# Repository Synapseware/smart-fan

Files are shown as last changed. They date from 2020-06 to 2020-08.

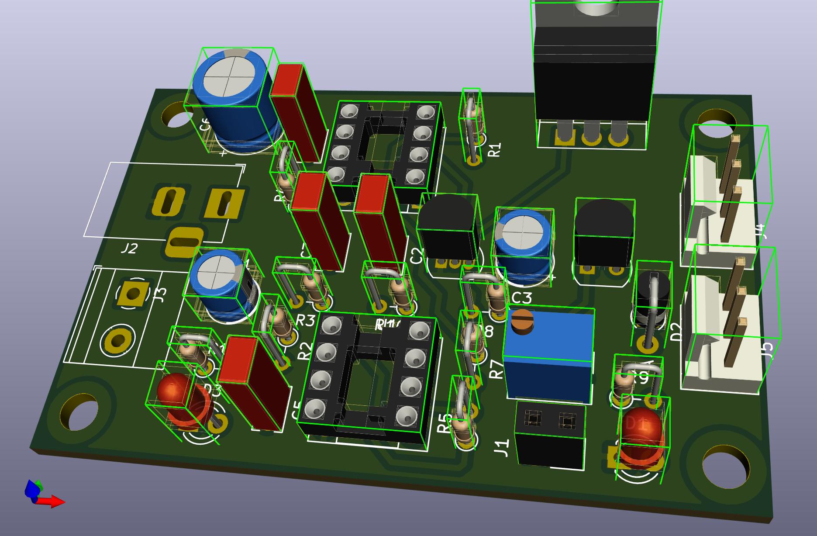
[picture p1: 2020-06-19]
analog-12v-only-smd/smart-fan-12v-only.jpg

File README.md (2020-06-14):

Smart-Fan
=========

Yet another fan project...

# Projects

## Analog
Simple analog fan controller (on/off) using a TMP35.

## Case Cooling
Smart fan controller using tachometer feedback and either PWM (4-pin) or voltage control (3-pin) and a variety of temperature sensors (analog, 1-wire, etc.).  Used to provide automatic temperature control for things like my printer enclosure for air circulation, inlet air control, etc.

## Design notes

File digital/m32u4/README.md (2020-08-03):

Arduino Leonardo ATMega32u4
===========================

Based on the m32u4 Leonardo board, this fan controller uses digital one-wire temperature sensors and a simple USB-UART for fan programming.

## Pin mappings
https://www.arduino.cc/en/Hacking/PinMapping32u4
```
Pin Name							Mapped Pin Name
1	PE6 (INT.6/AIN0)				Digital pin 7
2	UVcc							+5V
3	D-								RD-
4	D+								RD+
5	UGnd							UGND
6	UCap							UCAP
7	VUSB							VBus
8	(SS/PCINT0) PB0					RXLED
9	(PCINT1/SCLK) PB1				SCK
10	(PDI/PCINT2/MOSI) PB2			MOSI
11	(PDO/PCINT3/MISO) PB3			MISO
12	(PCINT7/OC0A/OC1C/#RTS) PB7		Digital pin 11 (PWM)
13	RESET							RESET
14	Vcc								+5V
15	GND								GND
16	XTAL2							XTAL2
17	XTAL1							XTAL1
18	(OC0B/SCL/INT0) PD0				Digital pin 3 (SCL)(PWM)
19	(SDA/INT1) PD1					Digital pin 2 (SDA)
20	(RX D1/AIN1/INT2) PD2			Digital pin 0 (RX)
21	(TXD1/INT3) PD3					Digital pin 1 (TX)
22	(XCK1/#CTS) PD5					TXLED
23	GND1							GND
24	AVCC							AVCC
25	(ICP1/ADC8) PD4					Digital pin 4
26	(T1/#OC4D/ADC9) PD6				Digital pin 12
27	(T0/OC4D/ADC10) PD7				Digital Pin 6 (PWM)
28	(ADC11/PCINT4) PB4				Digital pin 8
29	(PCINT5/OC1A/#OC4B/ADC12) PB5	Digital Pin 9 (PWM)
30	(PCINT6/OC1B/OC4B/ADC13) PB6	Digital Pin 10 (PWM)
31	(OC3A/#0C4A) PC6				Digital Pin 5 (PWM)
32	(ICP3/CLK0/)0C4A) PC7			Digital Pin 13 (PWM)
33	(#HWB) PE2						HWB
34	Vcc1							+5V
35	GND2							GND
36	(ADC7/TDI) PF7					Analog In 0
37	(ADC6/TDO) PF6					Analog In 1
38	(ADC5/TMS) PF5					Analog In 2
39	(ADC4/TCK) PF4					Analog In 3
40	(ADC1) PF1						Analog In 4
41	(ADC0) PF0						Analog In 5
42	AREF							AEF
43	GND3							GND
44	AVCC1							AVCC
```

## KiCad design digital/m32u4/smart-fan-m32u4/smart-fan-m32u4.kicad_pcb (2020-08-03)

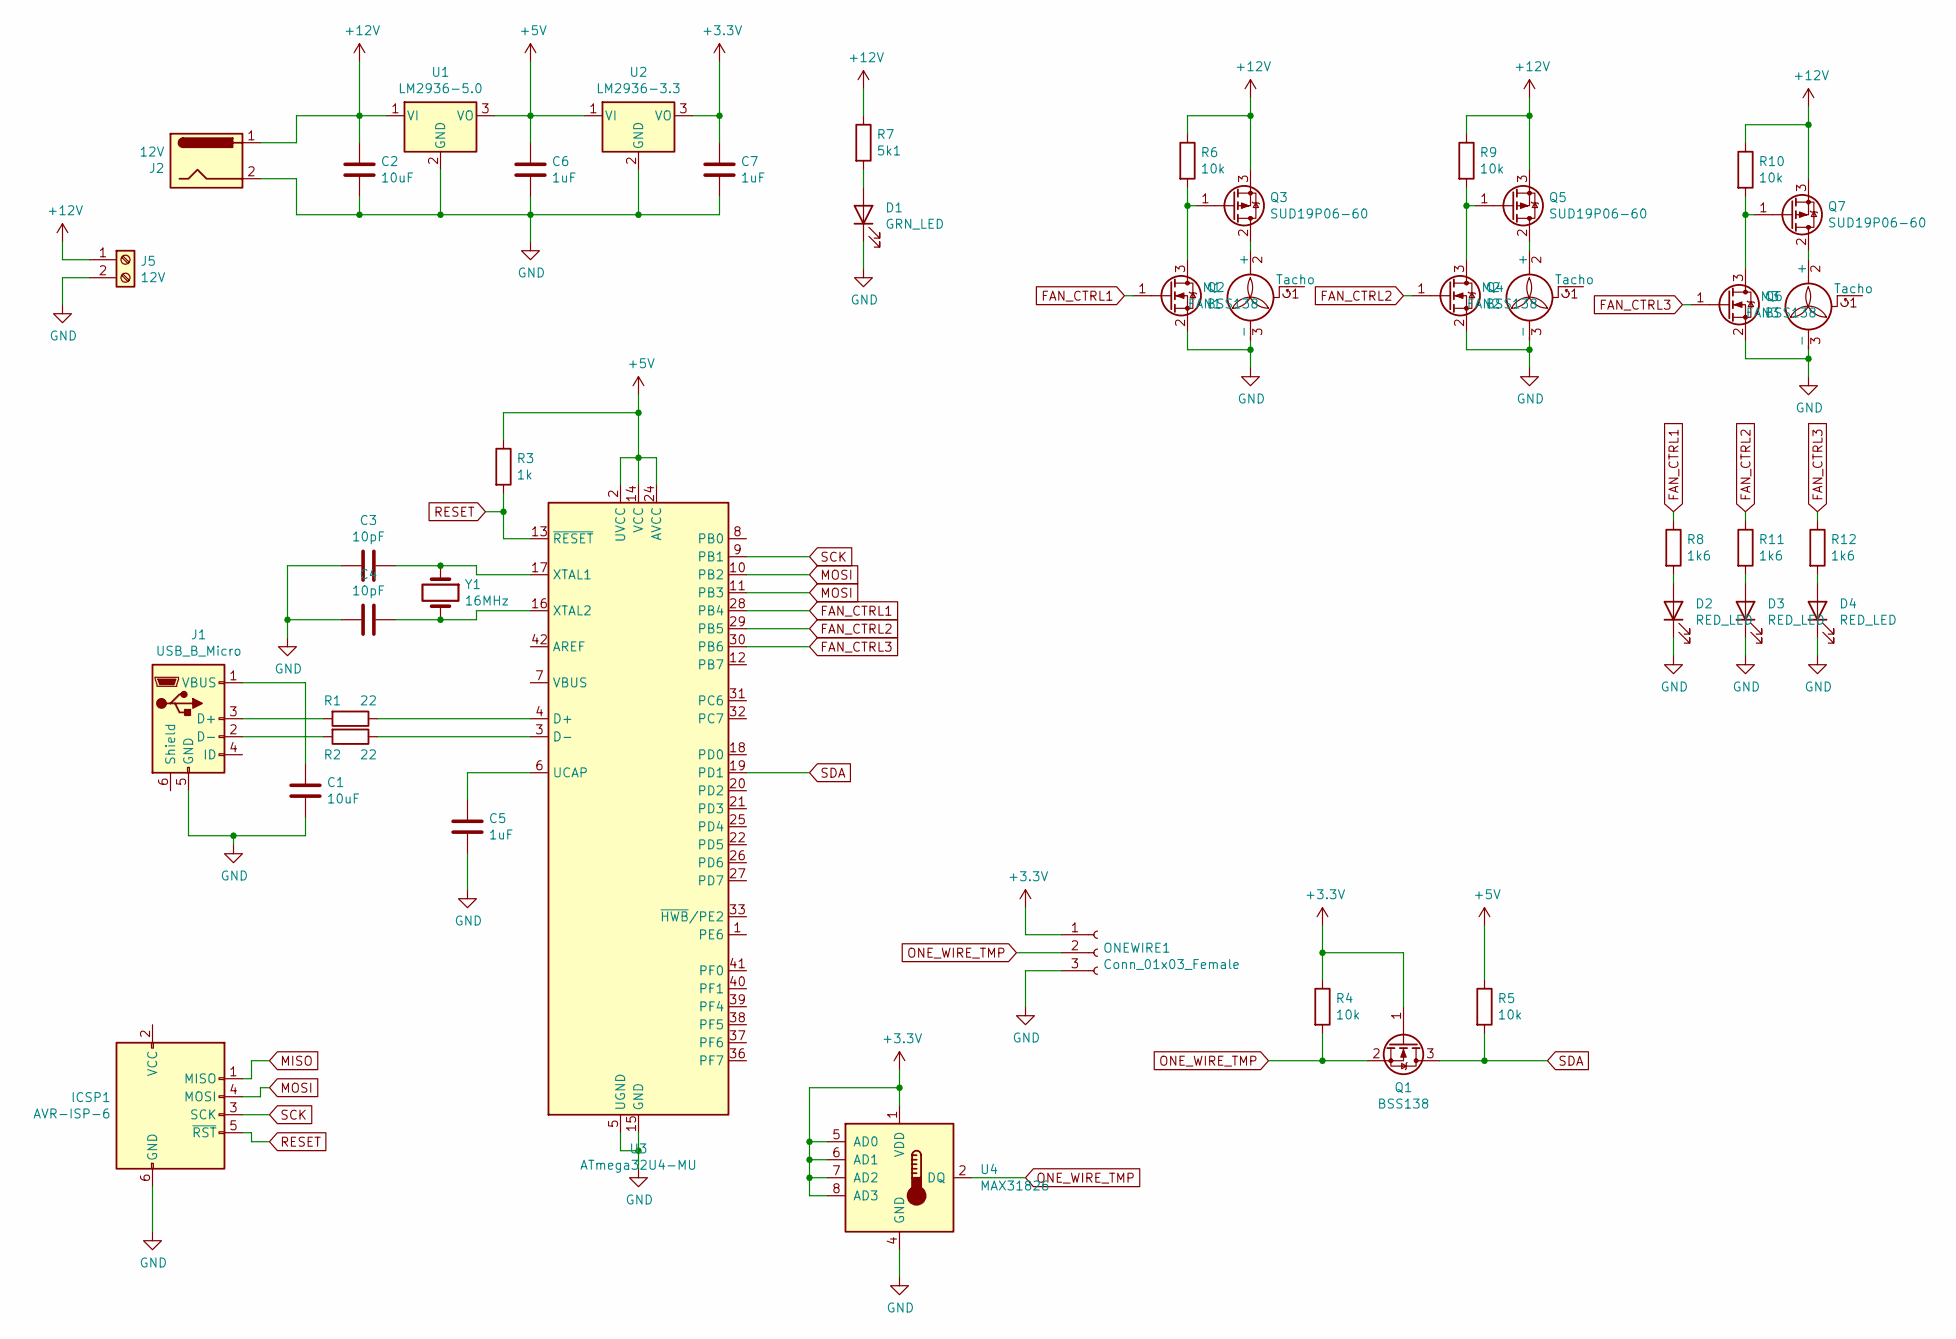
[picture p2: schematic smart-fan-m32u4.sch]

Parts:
C1, C2: 10uF; C_0805_2012Metric
C3, C4: 10pF; C_0805_2012Metric
C5, C6, C7: 1uF; C_0805_2012Metric
D1: GRN_LED; LED_0805_2012Metric
D2, D3, D4: RED_LED; LED_0805_2012Metric
ICSP1: AVR-ISP-6; PinHeader_2x03_P2.54mm_Vertical
J1: USB_B_Micro; USB_Micro-B_Amphenol_10104110_Horizontal
J2: 12V; BarrelJack_Horizontal
J5: 12V; TerminalBlock_Phoenix_MKDS-1,5-2-5.08_1x02_P5.08mm_Horizont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
M1: FAN1; FanPinHeader_1x03_P2.54mm_Vertical
M2: FAN2; FanPinHeader_1x03_P2.54mm_Vertical
M3: FAN3; FanPinHeader_1x03_P2.54mm_Vertical
ONEWIRE1: Conn_01x03_Female; PinSocket_1x03_P2.54mm_Vertical
Q1, Q2, Q4, Q6: BSS138; SOT-23
Q3, Q5, Q7: SUD19P06-60; TO-252-2
R1, R2: 22; R_0805_2012Metric
R3: 1k; R_0805_2012Metric
R4, R5, R6, R9, R10: 10k; R_0805_2012Metric
R7: 5k1; R_0805_2012Metric
R8, R11, R12: 1k6; R_0805_2012Metric
U1: LM2936-5.0; SOT-223-3_TabPin2
U2: LM2936-3.3; SOT-223-3_TabPin2
U3: ATmega32U4-MU; QFN-44-1EP_7x7mm_P0.5mm_EP5.2x5.2mm
U4: MAX31826; MSOP-8_3x3mm_P0.65mm
Y1: 16MHz; Crystal_SMD_0603-2Pin_6.0x3.5mm

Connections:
+3V3: C7.1, ONEWIRE1.1, Q1.1 (G), R4.1, U2.3 (VO), U4.1 (VDD), U4.5 (AD0), U4.6 (AD1), U4.7 (AD2), U4.8 (AD3)
+5V: C6.1, R3.1, R5.1, U1.3 (VO), U2.1 (VI), U3.2 (UVCC), U3.14 (VCC), U3.24 (AVCC), U3.34 (VCC), U3.44 (AVCC)
+12V: C2.1, J2.1, J5.1, Q3.3 (S), Q5.3 (S), Q7.3 (S), R6.1, R7.1, R9.1, R10.1, U1.1 (VI)
FAN_CTRL1: Q2.1 (G), R8.1, U3.28 (PB4)
FAN_CTRL2: Q4.1 (G), R11.1, U3.29 (PB5)
FAN_CTRL3: Q6.1 (G), R12.1, U3.30 (PB6)
GND: C1.2, C2.2, C3.2, C4.2, C5.2, C6.2, C7.2, D1.1 (K), D2.1 (K), D3.1 (K), D4.1 (K), ICSP1.6 (GND), J1.5 (GND), J2.2, J5.2, M1.3 (-), M2.3 (-), M3.3 (-), ONEWIRE1.3, Q2.2 (S), Q4.2 (S), Q6.2 (S), U1.2 (GND), U2.2 (GND), U3.5 (UGND), U3.15 (GND), U3.23 (GND), U3.35 (GND), U3.43 (GND), U3.45 (GND), U4.4 (GND)
MISO: ICSP1.1 (MISO)
MOSI: ICSP1.4 (MOSI), U3.10 (PB2), U3.11 (PB3)
unnamed: C1.1, J1.1 (VBUS)
unnamed: C3.1, U3.17 (XTAL1), Y1.1
unnamed: C4.1, U3.16 (XTAL2), Y1.2
unnamed: C5.1, U3.6 (UCAP)
unnamed: D1.2 (A), R7.2
unnamed: D2.2 (A), R8.2
unnamed: D3.2 (A), R11.2
unnamed: D4.2 (A), R12.2
unnamed: J1.2 (D-), R2.2
unnamed: J1.3 (D+), R1.2
unnamed: M1.2 (+), Q3.2 (D)
unnamed: M2.2 (+), Q5.2 (D)
unnamed: M3.2 (+), Q7.2 (D)
unnamed: Q2.3 (D), Q3.1 (G), R6.2
unnamed: Q4.3 (D), Q5.1 (G), R9.2
unnamed: Q6.3 (D), Q7.1 (G), R10.2
unnamed: R1.1, U3.4 (D+)
unnamed: R2.1, U3.3 (D-)
ONE_WIRE_TMP: ONEWIRE1.2, Q1.2 (S), R4.2, U4.2 (DQ)
RESET: ICSP1.5 (~RST), R3.2, U3.13 (~RESET)
SCK: ICSP1.3 (SCK), U3.9 (PB1)
SDA: Q1.3 (D), R5.2, U3.19 (PD1)

Board: 2 copper layers, 43 parts (0 on the bottom side), 30 nets, no tracks yet.

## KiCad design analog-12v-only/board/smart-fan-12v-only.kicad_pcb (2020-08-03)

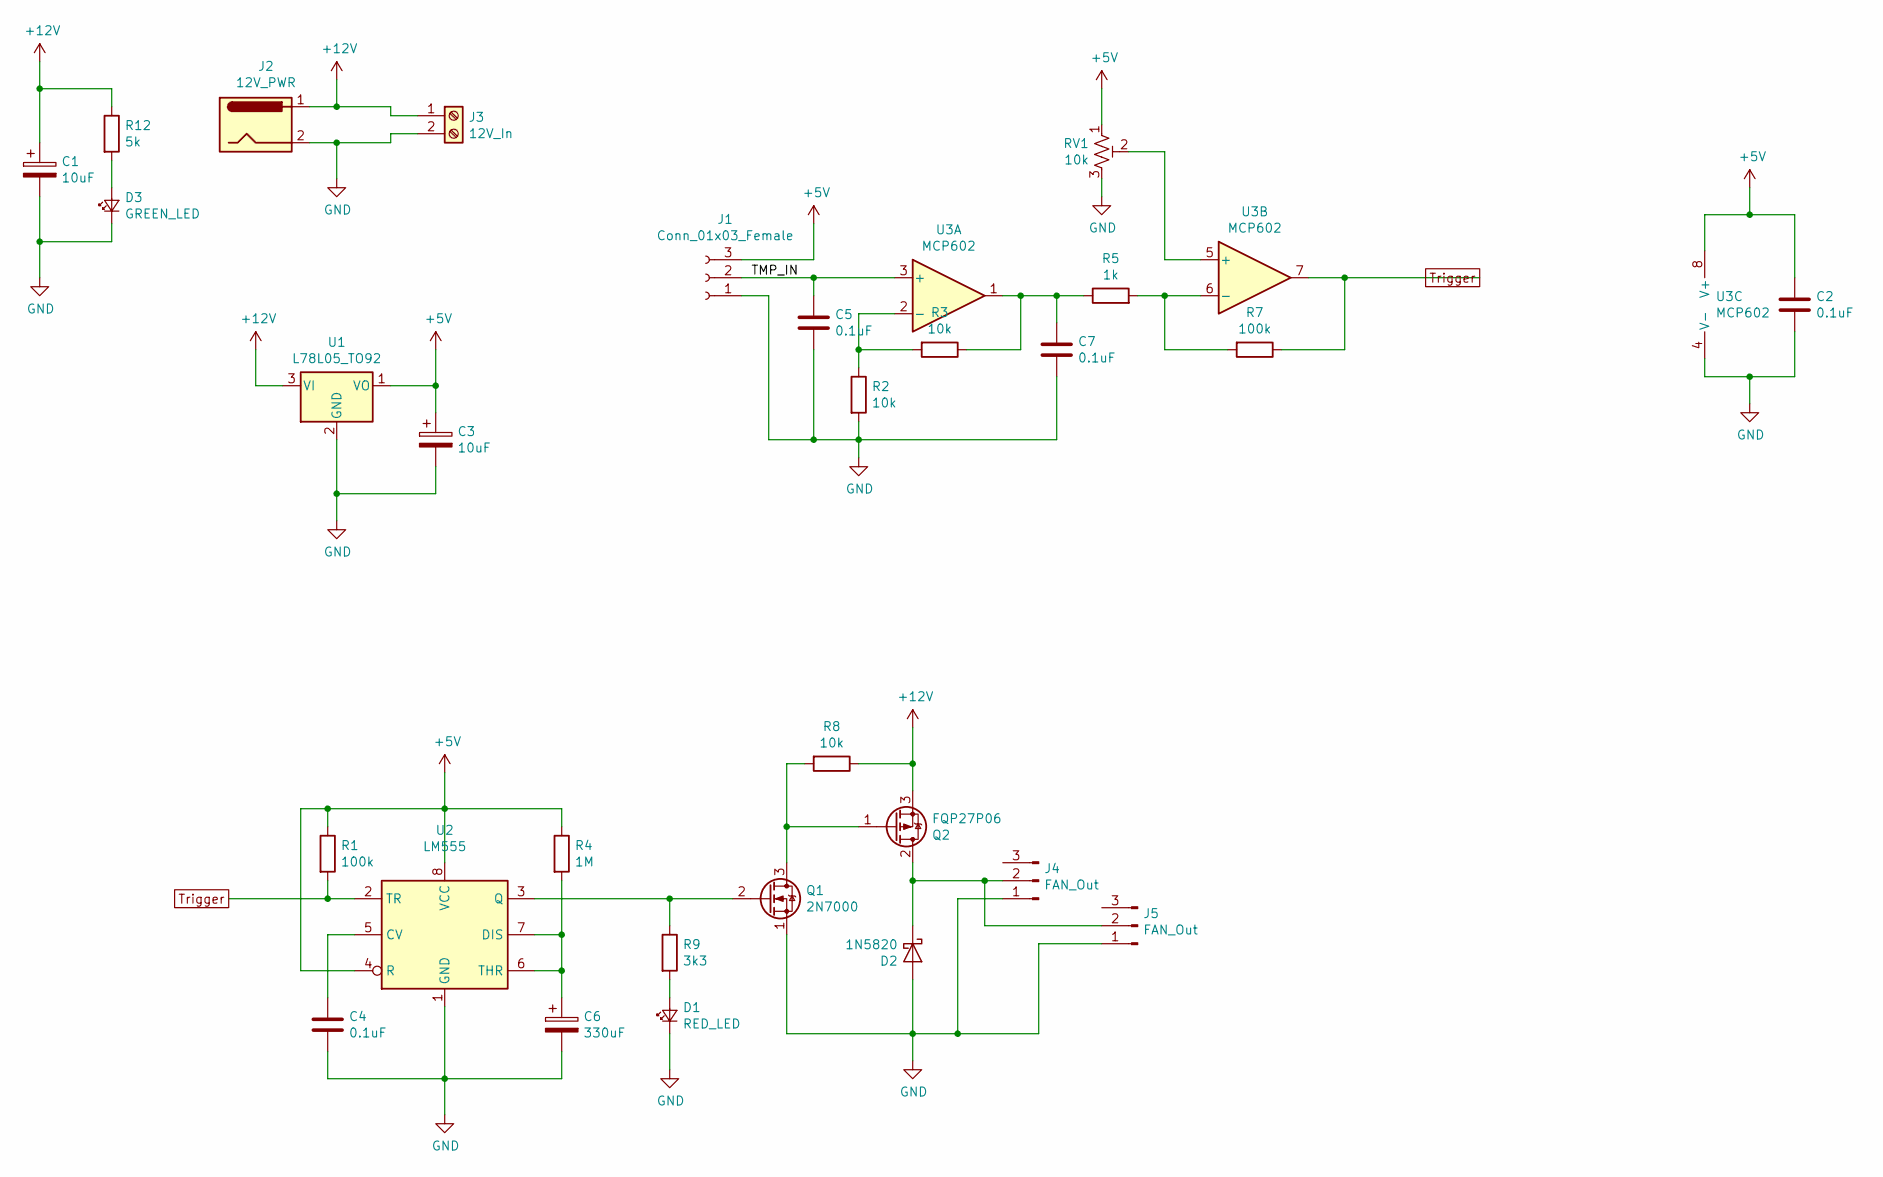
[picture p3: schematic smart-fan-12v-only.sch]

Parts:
C1, C3: 10uF; CP_Radial_D5.0mm_P2.00mm
C2, C4, C5, C7: 0.1uF; C_Rect_L4.0mm_W2.5mm_P2.50mm
C6: 330uF; CP_Radial_D7.5mm_P2.50mm
D1: RED_LED; LED_D3.0mm
D2: 1N5820; D_A-405_P2.54mm_Vertical_AnodeUp
D3: GREEN_LED; LED_D3.0mm
J1: Conn_01x03_Female; PinSocket_1x03_P2.54mm_Vertical
J2: 12V_PWR; BarrelJack_Horizontal
J3: 12V_In; TerminalBlock_Phoenix_MKDS-1,5-2_1x02_P5.00mm_Horizontal
J4, J5: FAN_Out; FanPinHeader_1x03_P2.54mm_Vertical
Q1: 2N7000; TO-92_Inline
Q2: FQP27P06; TO-251-3-1EP_Horizontal_TabDown
R1, R7: 100k; R_Axial_DIN0204_L3.6mm_D1.6mm_P2.54mm_Vertical
R2, R3, R8: 10k; R_Axial_DIN0204_L3.6mm_D1.6mm_P2.54mm_Vertical
R4: 1M; R_Axial_DIN0204_L3.6mm_D1.6mm_P2.54mm_Vertical
R5: 1k; R_Axial_DIN0204_L3.6mm_D1.6mm_P2.54mm_Vertical
R9: 3k3; R_Axial_DIN0204_L3.6mm_D1.6mm_P2.54mm_Vertical
R12: 5k; R_Axial_DIN0204_L3.6mm_D1.6mm_P2.54mm_Vertical
RV1: 10k; Potentiometer_Bourns_3266Y_Vertical
U1: L78L05_TO92; TO-92_Inline
U2: LM555; DIP-8_W7.62mm_Socket
U3: MCP602; DIP-8_W7.62mm_Socket

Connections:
+5V: C2.1, C3.1, J1.3, R1.1, R4.1, RV1.1, U1.1 (VO), U2.4 (R), U2.8 (VCC), U3.8 (V+)
+12V: C1.1, J2.1, J3.1, Q2.3 (S), R8.1, R12.1, U1.3 (VI)
/TMP_IN: C5.1, J1.2, U3.3 (+)
GND: C1.2, C2.2, C3.2, C4.2, C5.2, C6.2, C7.2, D1.1 (K), D2.2 (A), D3.1 (K), J1.1, J2.2, J3.2, J4.1, J5.1, Q1.1 (S), R2.2, RV1.3, U1.2 (GND), U2.1 (GND), U3.4 (V-)
unnamed: C4.1, U2.5 (CV)
unnamed: C6.1, R4.2, U2.6 (THR), U2.7 (DIS)
unnamed: C7.1, R3.1, R5.1, U3.1
unnamed: D1.2 (A), R9.2
unnamed: D2.1 (K), J4.2, J5.2, Q2.2 (D)
unnamed: D3.2 (A), R12.2
unnamed: Q1.2 (G), R9.1, U2.3 (Q)
unnamed: Q1.3 (D), Q2.1 (G), R8.2
unnamed: R2.1, R3.2, U3.2 (-)
unnamed: R5.2, R7.2, U3.6 (-)
unnamed: RV1.2, U3.5 (+)
Trigger: R1.2, R7.1, U2.2 (TR), U3.7

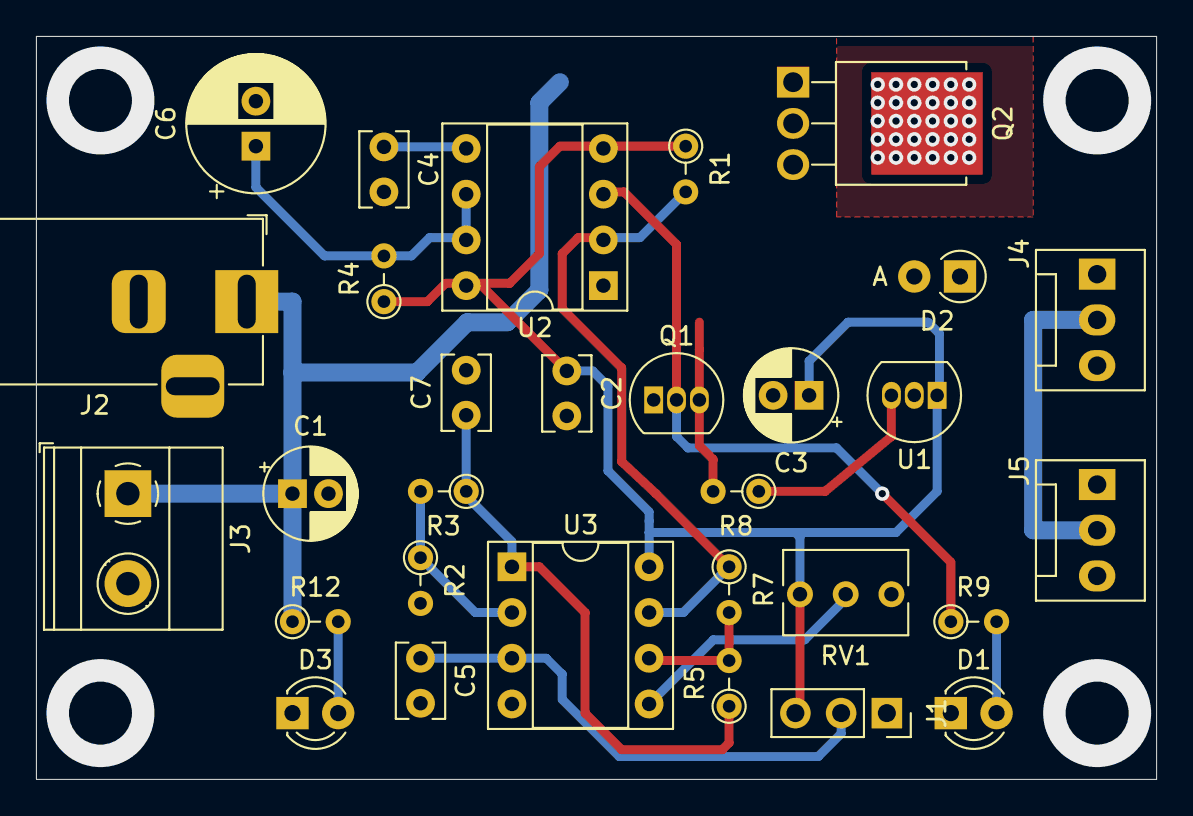
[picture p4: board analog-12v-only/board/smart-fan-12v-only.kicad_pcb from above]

Board: 2 copper layers, 62.2 x 41.3 mm, 30 parts (0 on the bottom side), 16 nets.

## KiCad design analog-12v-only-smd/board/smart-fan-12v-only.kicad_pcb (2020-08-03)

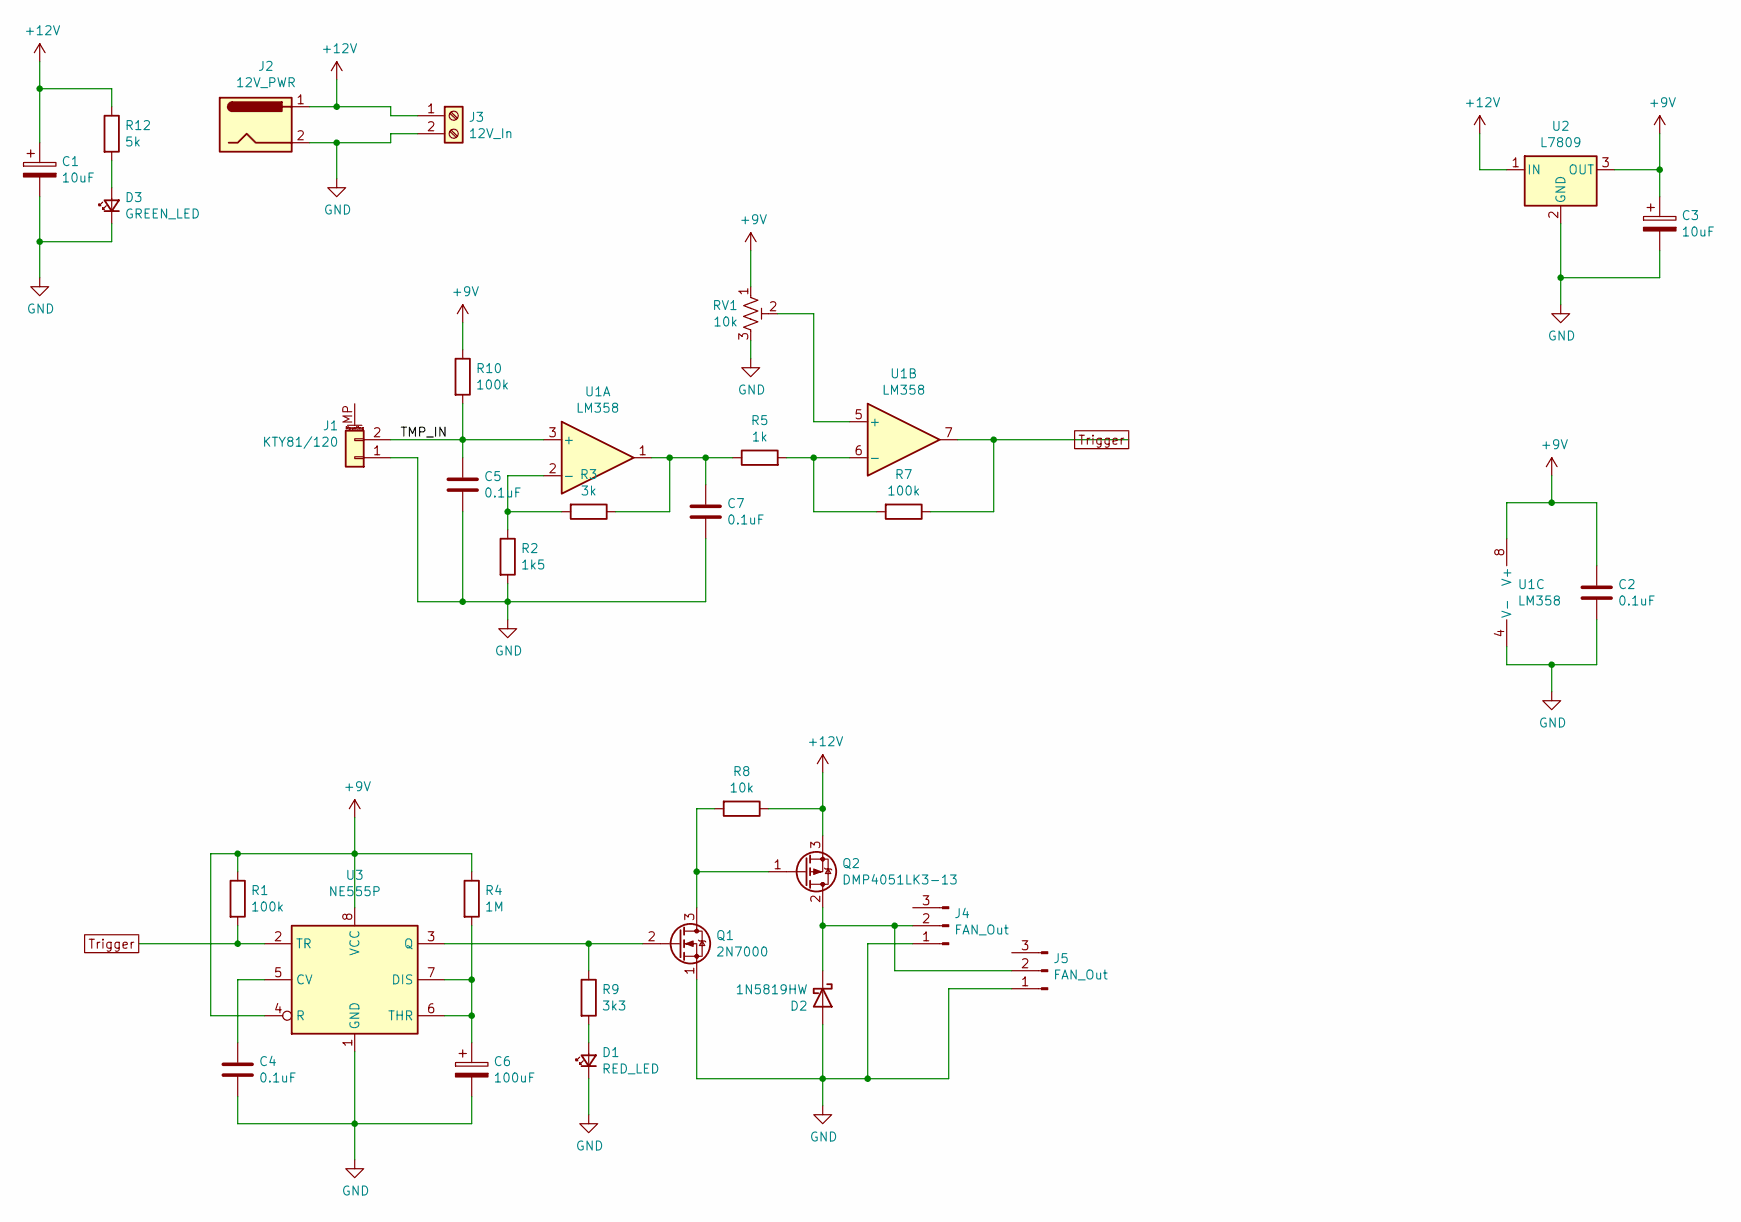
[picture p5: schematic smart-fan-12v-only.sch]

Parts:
C1, C3: 10uF; CP_Elec_3x5.3
C2, C4, C5, C7: 0.1uF; C_0805_2012Metric
C6: 100uF; CP_Elec_6.3x4.5
D1: RED_LED; LED_0805_2012Metric
D2: 1N5819HW; D_SOD-123
D3: GREEN_LED; LED_0805_2012Metric
J1: KTY81/120; PinSocket_1x02_P2.54mm_Vertical
J2: 12V_PWR; BarrelJack_Horizontal
J3: 12V_In; TerminalBlock_Phoenix_MKDS-3-2-5.08_1x02_P5.08mm_Horizontal
J4, J5: FAN_Out; FanPinHeader_1x03_P2.54mm_Vertical
Q1: 2N7000; SOT-23
Q2: DMP4051LK3-13; TO-252-2
R1, R7, R10: 100k; R_0805_2012Metric
R2: 1k5; R_0805_2012Metric
R3: 3k; R_0805_2012Metric
R4: 1M; R_0805_2012Metric
R5: 1k; R_0805_2012Metric
R8: 10k; R_0805_2012Metric
R9: 3k3; R_0805_2012Metric
R12: 5k; R_0805_2012Metric
RV1: 10k; Potentiometer_Bourns_3266Y_Vertical
U1: LM358; SO-8_3.9x4.9mm_P1.27mm
U2: L7809; SOT-89-3
U3: NE555P; SO-8_3.9x4.9mm_P1.27mm

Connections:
+9V: C2.1, C3.1, R1.1, R4.1, R10.1, RV1.1, U1.8 (V+), U2.3 (OUT), U3.4 (R), U3.8 (VCC)
+12V: C1.1, J2.1, J3.1, Q2.3 (S), R8.1, R12.1, U2.1 (IN)
/TMP_IN: C5.1, J1.2, R10.2, U1.3 (+)
GND: C1.2, C2.2, C3.2, C4.2, C5.2, C6.2, C7.2, D1.1 (K), D2.2 (A), D3.1 (K), J1.1, J2.2, J3.2, J4.1, J5.1, Q1.1 (S), R2.2, RV1.3, U1.4 (V-), U2.2 (GND), U3.1 (GND)
unnamed: C4.1, U3.5 (CV)
unnamed: C6.1, R4.2, U3.6 (THR), U3.7 (DIS)
unnamed: C7.1, R3.1, R5.1, U1.1
unnamed: D1.2 (A), R9.2
unnamed: D2.1 (K), J4.2, J5.2, Q2.2 (D)
unnamed: D3.2 (A), R12.2
unnamed: Q1.2 (G), R9.1, U3.3 (Q)
unnamed: Q1.3 (D), Q2.1 (G), R8.2
unnamed: R2.1, R3.2, U1.2 (-)
unnamed: R5.2, R7.2, U1.6 (-)
unnamed: RV1.2, U1.5 (+)
Trigger: R1.2, R7.1, U1.7, U3.2 (TR)

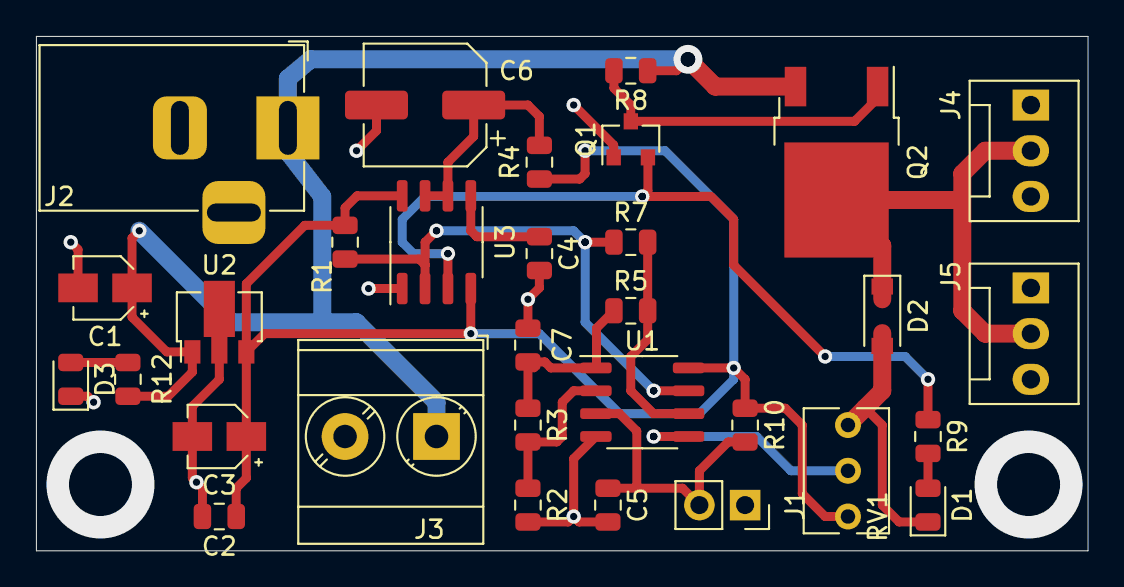
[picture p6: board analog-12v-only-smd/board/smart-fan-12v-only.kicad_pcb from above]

Board: 2 copper layers, 58.4 x 28.6 mm, 31 parts (0 on the bottom side), 16 nets.

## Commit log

2020-06-15 Working on analog board layout
    [smart-fan.kicad_pcb, smart-fan.sch]
2020-06-15 Improving board layout
    [smart-fan.kicad_pcb, smart-fan.sch]
2020-06-17 Board layout complete with ground planes and mounting holes
    [smart-fan.kicad_pcb, smart-fan.sch]
2020-06-18 Fix up 12v only analog fan controller
    [smart-fan-12v-only.kicad_pcb, smart-fan-12v-only.sch]
2020-06-19 Layout fixes and stable power
    [smart-fan-12v-only.kicad_pcb, smart-fan-12v-only.sch]
2020-06-20 Adding SMD board
    [smart-fan-12v-only.kicad_pcb, smart-fan-12v-only.sch]
2020-06-21 Fix board layout
    Power transistor drain-source swapped
    Flyback diode reversed
    [smart-fan-12v-only.kicad_pcb, smart-fan-12v-only.sch]
2020-06-28 WIP - m32u4 based controller
    [smart-fan-m32u4.kicad_pcb, smart-fan-m32u4.sch]
2020-06-28 Working on layout and adding 2 more fan channels
    [smart-fan-m32u4.kicad_pcb, smart-fan-m32u4.sch]
2020-08-03 WIP: Cleaning up board
    [smart-fan-12v-only.kicad_pcb, smart-fan-12v-only.sch, smart-fan.sch]
